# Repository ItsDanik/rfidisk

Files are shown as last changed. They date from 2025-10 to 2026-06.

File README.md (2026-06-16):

rfidisk_logo_hires

# 💾 RFIDisk — Physical App Launcher for Linux PC

**RFIDisk** turns RFID tags into *physical shortcuts* that launch games, apps, or scripts when inserted on a retro-styled "floppy drive" reader. Think of it as a cross between an RFID scanner and a USB floppy disk drive.  

https://github.com/user-attachments/assets/157f7cc6-f476-471f-b4b7-5301d1c28b9b

---

## What it is
This project is a combination of hardware and software:  

### Hardware
- An microcontroller device (Arduino), attached to an RFID reader module and an OLED display module, connected to the host machine via USB. It has its own 3D printed case design, resembling an external floppy disk drive.
- 3D Printed "Floppies" (they're not really floppy), with the RFID tag embedded in the print (invisible). Real floppies can be used instead, if you have an abundance of faulty ones.  

### Software
- The software is again a combination of two pieces of software:  
- One running on the arduino (we'll call it firmware).  
- The other one running on the host machine (Linux PC).  
- The two applications talk between them via Serial USB.
- Configuration and Tag Management is done via RFIDisk Manager (GUI App).

3D  

---

## How It Works
- Each RFID tag inside the disk corresponds to a command (e.g. `steam steam://rungameid/12345`).
1. When a disk is inserted in the drive, the Arduino firmware identifies it and notifies the host.  
2. The Python service looks up the tag’s command in `rfidisk_tags.json` and launches it.  
3. A notification is shown on the host machine.  
4. The OLED display updates in real time, showing metadata of the disk (user-configurable).  
5. When the disk is removed from the reader, the application is automatically terminated.  

This mode of operation closely resembles a cartridge-based game console system, only you don't have to reboot :)  






---

## WARNING!
> [!CAUTION]
Use this **at your own risk!!** This project contains a script that can pretty much execute whatever command the user wants. Do not import other people's configurations, except if you really know what you're doing. **Always** manually check the configuration file for malicious commands!

> [!IMPORTANT]
This project, including this README, are work in progress. There may be bugs, typos, errors, omissions etc.

---

## What you'll need
### Bill of Materials:

- 1x Arduino UNO (or compatible)  
- 1x 1.3" OLED 128x64 Display (**SH1106 controller**)  
- 1x RFID Reader Module (**MFRC522**)  
- 11x Jumper Wires ~15cm (Female to Male)  
- 1x USB Cable (type B to type A)
- 16x 4mm self-tapping M2 Screws  
- 4x 6mm self-tapping M2 Screws  
- 4x Rubber Feet  
- NFC NTAG213 25mm 13.56MHz (as many as you need, one per floppy)

### Tools:
- Soldering iron  
- 3D Printer  
- A PC running Linux  

---

## Hardware Assembly  

### Arduino Pinout  

Connect the devices to the arduino as shown below. 

> [!WARNING]  
> You will have to cut and solder on the RC522 board because of space restrictions, it won't fit the case otherwise.
> You can use connectors on all other connections (Arduino & OLED module).  

> [!CAUTION]  
> Connecting the RC522 board to 5V **WILL fry it!** Don't ask me how I know :)  
> Always double-check that 3.3V goes to RC522 and 5V goes to OLED module.  

```
RC522 VCC --- 3.3V  Arduino  
RC522 GND ---- GND  Arduino  
RC522 RST ------ 9  Arduino  
RC522 MISO ---- 12  Arduino  
RC522 MOSI ---- 11  Arduino  
RC522 SCK ----- 13  Arduino  
RC522 SDA ----- 10  Arduino  
 OLED VCC ----- 5V  Arduino  
 OLED GND ---- GND  Arduino  
 OLED SCL ----- A5  Arduino  
 OLED SDA ----- A4  Arduino  
```

###  Case

- Go to [https://makerworld.com/en/models/1875124-rfidisk-drive-disk](https://makerworld.com/en/models/1875124-rfidisk-drive-disk) and 3D print the project.  
- Screw the OLED module on the 3D Printed Shell using 4x 4mm screws.  
- Screw the two boards on the 3D Printed PCB Support Piece using 8x 4mm screws.  
- Screw the whole PCB Support to the top of the case (from the bottom) using 4x 4mm screws.  
- Screw the bottom 3D Printed part to the bottom of the shell using 4x 6mm screws.
- Stick the four rubber feet to the bottom of the case.
- Connect the device to the PC, using a USB type-B to type-A cable.

### RFIDisk Floppies

- Use the corresponding plate on the MakerWorld Project.
- Plate 4 is for single disk, plate 5 is for printing 4 disks in one go.
- The printing pauses on layer 7, that's when you go and stick the NFC tags on the designated area.
  Be careful to center the sticker. The sticker should not touch the walls of the area. Feel free
  to manually lower the bed using your printer's controls to get a better view/fit your hand.
- When you have placed the sticker(s) press resume. The printer will seal the NFC tags at the next layer.

> [!NOTE]
> You can also use real 3.5" floppy disks and stick the sticker at the center at the bottom (hub).
> If you experience weak signal and/or inconsistencies in reading, the metal surface of the disk is at fault.
> You can try to open carefully the disk and remove the whole disk, and stick the sticker through the hole on the inside.

---

## Software Installation / Configuration

### Project File Structure
This project consists of 10 files:  
```
- License             | Standard GNU GPL3.0 License  
- README.md           | What you're reading now.  
- floppy.png          | The icon that is being displayed in the desktop notifications.  
- install.sh          | Automatic installation script. You need to chmod +x it before you run it.  
- rfidisk.ino         | The arduino firmware. Written in C++. We will compile and upload this to the Arduino.  
- rfidisk.py          | The host software, running on our host machine. Wtieen in Python. This does the talking with the Arduino.  
- rfidisk_config.json | This is the settings file for the Python script (serial port, delays, notifications etc).  
- rfidisk_tags.json   | This is the RFID Tag database. Edit this file to configure RFID Tag behaviour.  
- rfidisk-manager.py  | The GUI that the user interacts with to configure RFIDisk and manage Tag entries.
- rfidisk_themes.py   | You can edit this file to add your own custom color scheme on RFIDisk Manager.  
- rfidisk.png         | RFIDisk asset image.  
```
>[!NOTE]  
>```rfidisk_config.json``` and ```rfidisk_tags.json``` are not included in the release or the repository.
>They are generated on first launch.  

---

## Download rfidisk
From ~/ or any subdirectory, type:  
```
git clone https://github.com/ItsDanik/rfidisk.git
cd rfidisk
```
>[!WARNING]
>It is suggested that you choose your home directory or any subdirectory in that folder!
>This is to ensure correct file permissions and save a lot of trouble.

---

## Installation using install script  
As of version 0.85 and later, there is an install script that can (hopefully) install everything with minimal user input.  
WARNING! Everything is beta, USE AT YOUR OWN RISK!!!  

```
chmod +x ./install.sh
./install.sh
```

>[!NOTE]
The script tries to autodetect distro/package manager, and automatically install all dependencies.  
If it stumbles, it will hopefully tell you what went wrong so you can manually install it and run the install script again.  

Log out and back in, or reboot. If everything went smoothly and you see "Ready/Insert Disk" on the device's OLED screen, congratulations!  

> [!NOTE]
> There is a 10 second delay in launching the app during boot. This is on purpose to ensure serial bus has settled and environment is set.  
> However, on some setups, there may be some instability (a couple of resets of the arduino) as the system enumerates the buses during boot.
> Give it a minute after a fresh boot/reboot and try again once the OLED screen consistently reads "Insert Disk".  

Skip to the "Configuring RFIDisk" section.  

## Updating RFIDisk
- From the install directory: 
```
git pull https://github.com/ItsDanik/rfidisk.git
chmod +x ./install.sh
./install.sh
```
The script should automatically detect the older version installed and will offer to update.  

> [!NOTE]
> All files (including the Firmware) are always updated on every release (even if there were no changes), to simplify version control and ensure that
> RFIDisk has the correct environment for its functions.  

## Uninstalling RFIDisk
- From the install directory:
```
./install.sh --uninstall
```

The app will not launch on next login, and the RFID Manager is removed from the start menu. Your settings and Tag Database remains saved.  
To remove everything (you will lose all your config!):  

```
cd ..
rm -rf rfidisk
```

---
## Manual Installation
If the install scripts fails, or you don't trust it, here are step by step instructions for manual installation of RFIDisk.  

### Prerequisites
The python script requires psutil and serial modules. Make sure to install them:  

```pip install pyserial psutil```  

>[!NOTE]
> If your distro whines when you use pip because it has an "externally managed python environment",
> install your libraries using your package manager (apt, dnf, pacman etc)

Also, you're going to need an Arduino dev environment. In this example we will use arduino-cli.  
The arduino sketch requires MFRC522, Adafruit GFX, and Adafruit SH110X libraries.  
Make sure to install them. If using arduino-cli:  

```
arduino-cli core install arduino:avr
arduino-cli lib install "Adafruit SH110X" "Adafruit GFX" MFRC522
``` 

The user should be able to get control of the serial port.  
This means that the user must be in the uucp or dialout group.  

```
sudo usermod -a -G dialout $(whoami)
sudo usermod -a -G uucp $(whoami)
```  

---

### Compiling and Uploading the arduino sketch  
If using arduino-cli, go into the directory of the project and type:  

```
arduino-cli compile rfidisk.ino -p /dev/ttyACM0 -b arduino:avr:uno
arduino-cli upload rfidisk.ino -p /dev/ttyACM0 -b arduino:avr:uno
```  

> [!WARNING]
> If your setup has another device path for the arduino, replace /dev/ttyACM0 with yours.  

If everything was succesful, the OLED Display should now show a logo (RFIDisk) and firmware version.  
To start RFIDisk manually, type:  
```
python3 ./rfidisk.py
```

---

## RFIDisk Manager
This is the app that you interact with to configure and manage RFIDisk.  
Open RFIDisk Manager via start menu.  

<img width="736" height="714" alt="2025-10-27T17:19:04,791128745+02:00" src="https://github.com/user-attachments/assets/de0971f7-7d53-4eab-9f25-93d7960ad6cb" />

### Configuring rfidisk
Open RFIDisk Manager (via start menu) and click on the Configuration Tab:  

<img width="427" height="311" alt="2025-10-27T17:23:16,570329816+02:00" src="https://github.com/user-attachments/assets/66e1eed4-a6e5-42bf-b207-2e9959f55ecf" />

```Theme```  

Select a color scheme for the RFIDisk Manager. The default installation includes Light, Dark and Catppuccin (Latte, Frappe, Macchiato, Mocha variants).  

>[!TIP]
>Themes are stored in rfidisk_themes.json. You can edit the file to add your own themes.

```Serial Port: /dev/ttyACM0```  

This is likely already correct. In case your device has a different path, enter it here.  
If have have more serial devices and want to set up a udev rule with a static custom path like /dev/rfidisk, to avoid mixups, keep reading.  

```Removal Delay (seconds): 0.0```  

This ensures that a disk is not ejected by mistake. If you reinsert the disk during that time, the removal is not registered, and the app is not terminated.  

```Disable Autolaunch```  

This changes the behaviour of RFIDisk to NOT autolaunch the command associated with the disk. See below, "CLI Mode" for details.

```Desktop Notifications```  

This enables desktop notifications when a disk is inserted. Disable it if you want to disable desktop notifications.   

```Notification Timeout (ms): 8000```  

This works only when desktop_notifications is true. Determines the amount of time (in ms) that the notification will be displayed for.  

```"Auto Launch Manager```

When this is enabled, RFIDisk Manager automatically gets launched when the user inserts a new (or unconfigured) Tag.  

### Tag Management  
You can manage your Tag entries in this tab (add, remove, edit).  
Changes take effect immediately. Keep reading for details.  

---

## Using RFIDisk

RFIDisk should start automatically upon login if you installed it using the script.  

- The app should initialize, and on the OLED screen of the device you should be able to see a "Ready/Insert Disk" message. Insert a floppy into the drive.
- RFIDisk Manager should automatically pop open with a new entry already created and the Tag ID field automatically completed. Remove the disk now and edit the followind fields:  

<img width="378" height="262" alt="RFIDisk Manager New Tag" src="https://github.com/user-attachments/assets/38867cf5-7aa0-497f-9bf9-6268a00593ee" />

The Tag ID ("a1b2c3d4") at the top will be different and is the unique ID of the NFC tag. Don't touch this value.  
Launch command: Type here the command you want to execute when this disk is inserted. You can also browse for the executable.  
Display Line 1-4: These are the four lines of text that will be displayed on the OLED screen when this disk gets inserted.  
Usually the first two lines are used for the title of the application, Line 3 for release year and Line 4 for Developer/Publisher.  
Terminate command: Useful when launching Steam games (keep reading).  

> [!NOTE]
> - "Display Line 1" and "Display Line 2" get truncated at 20 characters.  
> - "Display Line 3" and "Display Line 4" get truncated at 14 characters (to make room for the icon).

Here is an example of an entry, properly configured and formatted:  

<img width="458" height="215" alt="RFIDisk Manager Full Tag" src="https://github.com/user-attachments/assets/12a1846b-84c0-450a-9090-86f507bb3483" />

>[!TIP]
>We can leave the "Terminate Command" blank for all native linux titles. The script is aware of the whole process tree and can sucessfully track and terminate most applications.  

Click on "Save Changes", quit the manager and insert the disk. The application should now launch!  
Remove the disk and the application closes.  
Repeat the configuration proccess for as many disks as you need.  

---

## Using RFIDisk (CLI mode)

If you disable autolaunch, you can control RFIDisk via a terminal, resembling the way disk drives worked in 8-bit home micros. With the daemon running, use the following command line arguments:

- ```rfidisk --list``` to display disk info
- ```rfidisk --load``` to launch the app corresponding to the Tag entry of the disk
- ```rfidisk --list-title``` to display the title of the disk entry in a single line format (useful for displaying in widgets like waybar etc).
- ```rfidisk --help``` displays a help message.  

> [!TIP]
> If you remove the disk while the application is running, it still terminates the app.

---

## Post-installation optimizations

### Create udev rules for static device path
If you have more than one serial devices, they might get mixed up if you rely on /dev/ttyACM0 path.  
We need to create a unique device path for the arduino.  
We'll create two udev rules, let's start with one that ensures USB serial ownership:  
```
sudo nano /etc/udev/rules.d/90-tty-acm.rules  
```
Paste this into the empty new file:  
```
SUBSYSTEM=="tty", KERNEL=="ttyACM[0-9]*", GROUP="uucp", MODE="0660", TAG+="uaccess"
```
Save the file (Ctrl-X, y)  

Now, another to set the symlink:  
```
sudo nano /etc/udev/rules.d/99-custom-serial.rules
```
Paste this into the empty new file:  
```
SUBSYSTEM=="tty", ATTRS{idVendor}=="2341", ATTRS{idProduct}=="0043", \
  SYMLINK+="rfidisk", GROUP="uucp", MODE="0660", TAG+="uaccess"
```
Save the file (Ctrl-X, y)

To apply:  
```
sudo udevadm control --reload-rules
sudo udevadm trigger
sudo udevadm settle
```
Unplug the RFIDisk drive and plug it back in. You should now see:  
```
ls -l /dev/rifidisk
```

If successful, remember to update the rfidisk_config.json file:  
```
"serial_port": "/dev/rfidisk",
```

---

## Bugs / Quirks:
### Proton Quirks
When an application is launched via proton (ie Windows games), during the USB ports enumeration on the host machine get reset, causing the arduino to resets briefly momentarily. This is a known issue with Proton, you can check it out [here](https://github.com/ValveSoftware/Proton/issues/6927).  
To combat this, as a workaround, an overly-complex connection recovery routine has been implemented, to avoid double launching of an app, and double notifications etc. It seems to be working ok, but it is a hack. If anyone finds a better way to handle this, like prevent the USB device from disconnecting when Proton initializes (completely hiding a USB port from proton?), please let me know.  

---

### Steam Games
To launch steam games, in the "command" field of the entry, use:  

```steam steam://rungameid/1234567```

where "1234567" is the gameid of the game you want to play. To find the gameid, just look at the url address of the Store page of the game. For example, Cyberpunk 2077's store page URL is  

```https://store.steampowered.com/app/1091500/Cyberpunk_2077/```  

This means, that the gameid of Cyberpunk 2077 is 1091500. But also, terminating games that were launched cannot be automated. We have to manually specify a "terminate" command, that's what this field is reserved for in rfid_config.json entries. To determine the command:  

- Run the game manually
- Open a proccess monitor (htop, btop etc)
- Find the name of the process
- The terminate command is "killall (name of the process)"
In the example of Cyberpunk 2077, the proccess name is "GameThread".

After all this work, now we can build a Steam game entry:

<img width="380" height="217" alt="2025-10-14T18:30:53,591035808+03:00" src="https://github.com/user-attachments/assets/3febd89b-1f19-4c17-a427-bbf8b1351b25" />

---

### TODO/Ideas List

- Explore GameScope support (test game launching and make use of GameScope notification system).  
- Potentially package it as a DeckyLoader plugin?  

If ever:  
- Find a solution for the known issue with Proton (USB Momentarily Disconnects and Arduino reboots).

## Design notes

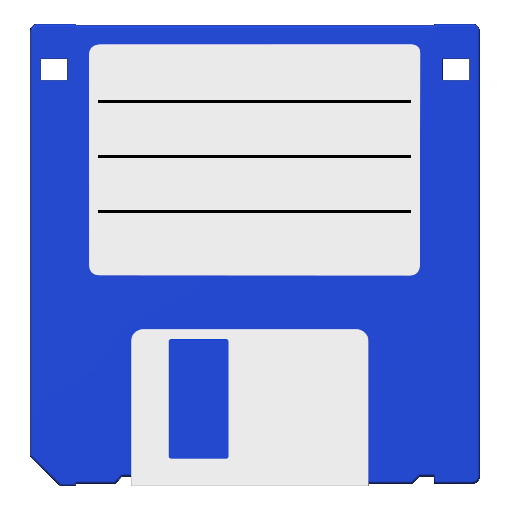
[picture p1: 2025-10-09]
floppy.png

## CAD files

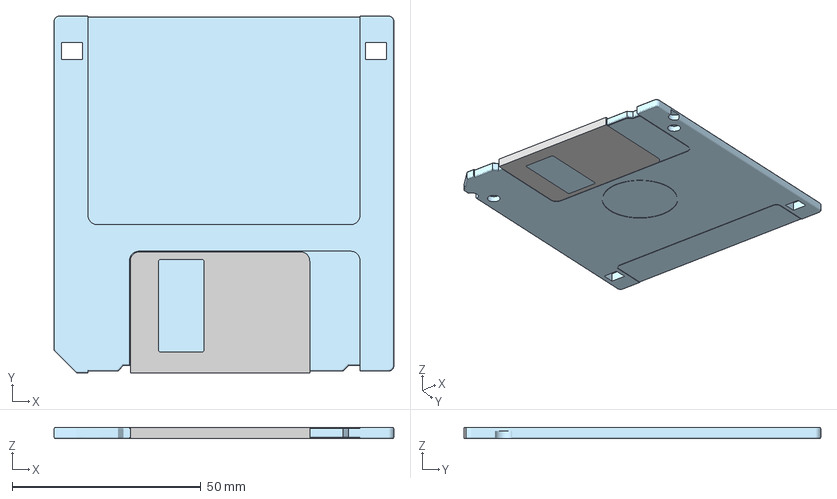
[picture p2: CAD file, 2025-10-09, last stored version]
3MF/RFIDisk V2.3mf
90.0 x 94.5 x 3.00 mm
Clip

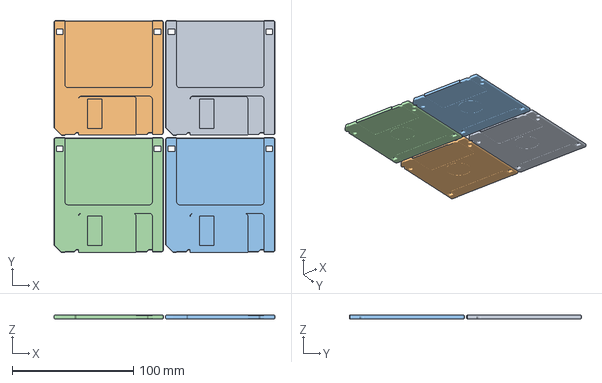
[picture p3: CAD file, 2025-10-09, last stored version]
danik floppy.3mf
182.0 x 191.0 x 3.00 mm
Assembly x 4

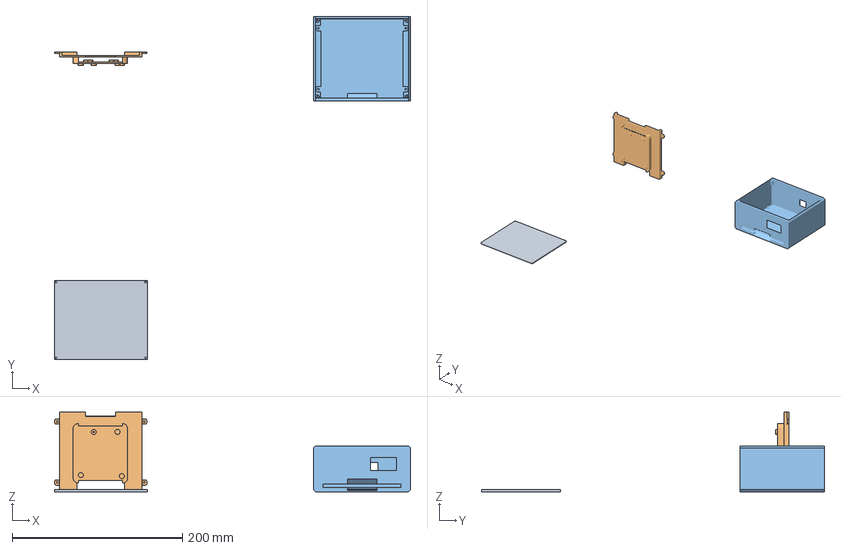
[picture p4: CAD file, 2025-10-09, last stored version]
Floppy RFID Scanner.3mf
419.1 x 403.3 x 93.5 mm
Bottom
Floppy RFID - PCB Support
RFID Floppy Shell

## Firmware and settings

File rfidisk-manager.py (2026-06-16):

#!/usr/bin/env python3
import tkinter as tk
from tkinter import ttk, messagebox, filedialog, simpledialog
import json
import os
import subprocess
import sys
import socket
import psutil
import time
import threading
import tempfile
from PIL import Image, ImageTk
import webbrowser

# Directory where this script lives, so the manager works regardless of CWD
SCRIPT_DIR = os.path.dirname(os.path.abspath(__file__))

# Use absolute paths for all data files (do not rely on the current directory)
TAGS_FILE = os.path.join(SCRIPT_DIR, "rfidisk_tags.json")
CONFIG_FILE = os.path.join(SCRIPT_DIR, "rfidisk_config.json")
THEME_FILE = os.path.join(SCRIPT_DIR, "rfidisk_theme.json")
VERSION_FILE = os.path.join(SCRIPT_DIR, "version")
LOGO_FILE = os.path.join(SCRIPT_DIR, "rfidisk.png")
LOCK_PORT = 47821
GITHUB_URL = "https://github.com/ItsDanik/rfidisk"


def read_version():
    """Read the version string from the shared 'version' file"""
    try:
        with open(VERSION_FILE, 'r') as f:
            return f.read().strip()
    except Exception:
        return "unknown"


def atomic_write_json(path, data):
    """Write JSON to path atomically.

    Writes to a temp file in the same directory, fsyncs it, then os.replace()s
    it over the target so a crash mid-write can never corrupt the existing file.
    """
    dir_name = os.path.dirname(path) or "."
    fd, tmp_path = tempfile.mkstemp(dir=dir_name, prefix=".tmp-", suffix=".json")
    try:
        with os.fdopen(fd, 'w') as f:
            json.dump(data, f, indent=2)
            f.flush()
            os.fsync(f.fileno())
        os.replace(tmp_path, path)
    except Exception:
        try:
            os.remove(tmp_path)
        except OSError:
            pass
        raise


# Version number (single source of truth: the 'version' file)
VERSION = read_version()

# Default fallback theme with semantic UI element names
COLORS = {
    # Background colors
    "bg_primary": "#1e1e2e",
    "bg_secondary": "#181825",
    "bg_tertiary": "#11111b",
    
    # Text colors
    "text_primary": "#cdd6f4",
    "text_secondary": "#bac2de",
    "text_tertiary": "#a6adc8",
    "text_warning": "#f38ba8",
    "text_success": "#a6e3a1",
    
    # Surface colors
    "surface_primary": "#313244",
    "surface_secondary": "#45475a",
    "surface_tertiary": "#585b70",
    
    # Border colors
    "border_primary": "#313244",
    "border_secondary": "#45475a",
    
    # Accent colors
    "accent_primary": "#89b4fa",
    "accent_secondary": "#74c7ec",
    "accent_success": "#a6e3a1",
    "accent_warning": "#f9e2af",
    "accent_error": "#f38ba8",
    "accent_highlight": "#fab387"
}

class SingletonApp:
    """Prevent multiple instances and handle inter-process communication"""
    def __init__(self):
        self.socket = None
        self.is_primary = False
        self.listening = False
        
    def acquire_lock(self):
        """Try to bind to a socket - if successful, we're the first instance"""
        try:
            self.socket = socket.socket(socket.AF_INET, socket.SOCK_STREAM)
            self.socket.setsockopt(socket.SOL_SOCKET, socket.SO_REUSEADDR, 1)
            self.socket.bind(('localhost', LOCK_PORT))
            self.socket.listen(1)
            self.socket.setblocking(False)
            self.is_primary = True
            return True
        except socket.error:
            return False
    
    def send_to_primary(self, tag_id=None):
        """Send a message to the primary instance"""
        try:
            client_socket = socket.socket(socket.AF_INET, socket.SOCK_STREAM)
            client_socket.settimeout(1.0)
            client_socket.connect(('localhost', LOCK_PORT))
            if tag_id:
                client_socket.send(f"EDIT:{tag_id}".encode())
            else:
                client_socket.send("FOCUS".encode())
            client_socket.close()
            return True
        except socket.error:
            return False
    
    def check_for_messages(self):
        """Check for incoming messages from other instances"""
        if not self.is_primary or not self.socket or not self.listening:
            return None
            
        try:
            client, addr = self.socket.accept()
            client.setblocking(True)
            data = client.recv(1024).decode().strip()
            client.close()
            return data
        except BlockingIOError:
            return None
        except socket.error:
            return None
    
    def start_listening(self):
        """Start listening for messages"""
        self.listening = True
    
    def stop_listening(self):
        """Stop listening for messages"""
        self.listening = False
    
    def cleanup(self):
        """Clean up socket resources"""
        self.stop_listening()
        if self.socket:
            self.socket.close()
            self.socket = None

class TagManager:
    def __init__(self, root):
        self.root = root
        self.root.title(f"RFIDisk Tag Manager v{VERSION}")
        self.root.geometry("740x720")
        
        # Load theme configuration
        self.themes = {}
        self.current_theme_name = "Catppuccin Mocha"
        self.load_theme_config()
        
        # Singleton management
        self.singleton = SingletonApp()
        self.setup_singleton()
        
        self.tags = self.load_tags()
        self.config = self.load_config()
        self.current_tag = None
        self.display_mode = "line1"

        # Live disk monitoring state (populated by the background `rfidisk --list` poller)
        self.inserted_tag_id = None          # tag_id of the currently inserted disk (None if empty)
        self.inserted_blank_tag_id = None    # set when the inserted disk is blank/unassigned
        self._highlight_tag_id = None        # tag_id to visually mark in the list (inserted + registered)
        self._disk_monitor_stop = threading.Event()

        # Load logo image
        self.logo_image = None
        self.load_logo()

        self.create_widgets()
        self.refresh_tag_list()

        # Start IPC handler after UI is fully set up
        self.root.after(100, self.setup_ipc_handler)

        # Start polling the inserted disk's contents via `rfidisk --list`
        self.start_disk_monitor()
    
    def load_theme_config(self):
        """Load theme configuration from file"""
        global COLORS
        
        try:
            with open(THEME_FILE, 'r') as f:
                theme_config = json.load(f)
            
            # Load available themes
            self.themes = theme_config.get("themes", {})
            
            # Get current theme name
            self.current_theme_name = theme_config.get("current_theme", "Catppuccin Mocha")
            
            # Load current theme colors
            if self.current_theme_name in self.themes:
                COLORS = self.themes[self.current_theme_name].copy()
                print(f"Loaded theme: {self.current_theme_name}")

                # Apply the color scheme
                self.configure_theme()

            else:
                print(f"Theme '{self.current_theme_name}' not found in theme file")
                
        except Exception as e:
            print(f"Failed to load theme config: {e}")
    
    def save_theme_config(self, theme_name):
        """Save current theme to configuration file"""
        try:
            with open(THEME_FILE, 'r') as f:
                theme_config = json.load(f)
            
            theme_config["current_theme"] = theme_name

            atomic_write_json(THEME_FILE, theme_config)

            print(f"Theme saved: {theme_name}")
            return True
        except Exception as e:
            print(f"Failed to save theme config: {e}")
            return False
    
    def change_theme(self, theme_name):
        """Change the current theme"""
        global COLORS
        
        if theme_name in self.themes:
            # Update global colors
            COLORS = self.themes[theme_name].copy()
            self.current_theme_name = theme_name
            
            # Save theme selection
            self.save_theme_config(theme_name)
            
            # Reconfigure theme
            self.configure_theme()
            
            # Update UI elements that need manual color updates
            self.update_theme_colors()
            
            return True
        else:
            return False
    
    def update_theme_colors(self):
        """Update UI elements that need manual color updates after theme change"""
        # Update root window background
        self.root.configure(bg=COLORS["bg_primary"])
        
        # Update warning labels and other non-ttk widgets
        for widget in self.root.winfo_children():
            self._update_widget_colors(widget)
    
    def _update_widget_colors(self, widget):
        """Recursively update widget colors"""
        try:
            if isinstance(widget, tk.Label):
                # Update background
                if widget.cget('bg') in [COLORS["bg_primary"], COLORS["bg_secondary"], COLORS["bg_tertiary"]]:
                    widget.configure(bg=COLORS["bg_primary"])
                
                # Update text colors
                current_fg = widget.cget('fg')
                if current_fg == COLORS.get("text_warning", "#f38ba8"):
                    widget.configure(fg=COLORS["text_warning"])
                elif current_fg == COLORS.get("accent_highlight", "#fab387"):
                    widget.configure(fg=COLORS["accent_highlight"])
                else:
                    widget.configure(fg=COLORS["text_primary"])
                    
        except tk.TclError:
            pass
        
        # Recursively update child widgets
        for child in widget.winfo_children():
            self._update_widget_colors(child)
    
    def load_logo(self):
        """Load the RFIDisk logo image"""
        logo_path = LOGO_FILE
        if os.path.exists(logo_path):
            try:
                image = Image.open(logo_path)
                if image.size != (400, 100):
                    image = image.resize((400, 100), Image.Resampling.LANCZOS)
                self.logo_image = ImageTk.PhotoImage(image)
            except Exception as e:
                print(f"Failed to load logo: {e}")
                self.logo_image = None
        else:
            print(f"Logo file not found: {logo_path}")
            self.logo_image = None
    
    def open_github(self):
        """Open the GitHub repository in the default web browser"""
        webbrowser.open(GITHUB_URL)
    
    def create_clickable_logo(self, parent):
        """Create a clickable logo that opens the GitHub repository"""
        if self.logo_image:
            logo_label = tk.Label(parent, image=self.logo_image, bg=COLORS["bg_primary"], cursor="hand2")
            logo_label.pack(pady=(0, 10))
            
            logo_label.bind("<Button-1>", lambda e: self.open_github())
            
            def on_enter(e):
                logo_label.config(bg=COLORS["surface_primary"])
            
            def on_leave(e):
                logo_label.config(bg=COLORS["bg_primary"])
            
            logo_label.bind("<Enter>", on_enter)
            logo_label.bind("<Leave>", on_leave)
            
            return logo_label
        return None
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

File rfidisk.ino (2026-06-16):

#include <SPI.h>
#include <MFRC522.h>
#include <Wire.h>
#include <EEPROM.h>
#include <Adafruit_GFX.h>
#include <Adafruit_SH110X.h>

#define RST_PIN 9
#define SS_PIN 10

Adafruit_SH1106G display(128, 64, &Wire, -1);
MFRC522 mfrc522(SS_PIN, RST_PIN);

bool tagPresent = false;
String lastTagUid = "";
const char version[] PROGMEM = "v0.97";

// OLED burn-in protection: idle dim / screen-off timers (set over serial via "C|")
unsigned long lastActivity = 0;
unsigned long dimDelayMs = 0;        // 0 = disabled
unsigned long offDelayMs = 0;        // 0 = disabled
byte powerState = 0;                 // 0 = active, 1 = dimmed, 2 = off
const byte CONTRAST_FULL = 0xCF;     // SH1106 default brightness
const byte CONTRAST_DIM  = 0x10;

// EEPROM persistence for the idle timers (survives reboots / works before the
// daemon connects). Signature byte guards against reading an uninitialised chip.
#define EE_SIG_ADDR 0
#define EE_DIM_ADDR 1
#define EE_OFF_ADDR 5
#define EE_SIG      0xA7

const unsigned char rfidisk_logo[] PROGMEM = {
0xfc, 0x7f, 0x77, 0xe1, 0xc0, 0x1c, 0x00, 0xe6, 0x70, 0x77, 0x31, 0xc0, 0x1c, 0x00, 0xe6, 0x70, 
	0x77, 0x18, 0x00, 0x1c, 0x00, 0xe7, 0x70, 0x77, 0x19, 0xc7, 0x1c, 0xc0, 0xe6, 0x70, 0x77, 0x19, 
	0xcd, 0x9d, 0x80, 0xe6, 0x7f, 0x77, 0x19, 0xdc, 0x1d, 0x80, 0xfc, 0x70, 0x77, 0x19, 0xcf, 0x1f, 
	0x00, 0xec, 0x70, 0x77, 0x19, 0xc7, 0x9f, 0x00, 0xe4, 0x70, 0x77, 0x19, 0xc1, 0x9f, 0x80, 0xe6, 
	0x70, 0x77, 0x31, 0xd9, 0x9d, 0x80, 0xe7, 0x70, 0x77, 0xe1, 0xcf, 0x1c, 0xc0
};

// 'icon_floppy', 24x24px
const unsigned char floppy_icon[] PROGMEM = {
	0x7f, 0xff, 0xfe, 0x40, 0x00, 0x02, 0x47, 0xff, 0xe2, 0x57, 0xff, 0xea, 0x47, 0xff, 0xe2, 0x47, 
	0xff, 0xe2, 0x47, 0xff, 0xe2, 0x47, 0xff, 0xe2, 0x47, 0xff, 0xe2, 0x47, 0xff, 0xe2, 0x47, 0xff, 
	0xe2, 0x47, 0xff, 0xe2, 0x43, 0xff, 0xc2, 0x40, 0x00, 0x02, 0x40, 0x00, 0x02, 0x41, 0xff, 0x82, 
	0x41, 0x1f, 0x82, 0x41, 0x1f, 0x82, 0x41, 0x1f, 0x82, 0x41, 0x1f, 0x82, 0x41, 0x1f, 0x82, 0x21, 
	0xff, 0x82, 0x10, 0x00, 0x02, 0x0f, 0xff, 0xfe
};

// 'icon_steam', 24x24px
const unsigned char steam_icon[] PROGMEM = {
	0x00, 0x7e, 0x00, 0x01, 0xff, 0x80, 0x07, 0xff, 0xe0, 0x0f, 0xff, 0xf0, 0x1f, 0xfc, 0x38, 0x3f, 
	0xf0, 0x0c, 0x3f, 0xf3, 0xcc, 0x7f, 0xe4, 0x26, 0x7f, 0xe4, 0x26, 0xff, 0xe4, 0x27, 0xff, 0xc4, 
	0x27, 0x7f, 0xc3, 0xcf, 0x0f, 0x80, 0x0f, 0x02, 0x00, 0x3f, 0x00, 0xc3, 0xff, 0x00, 0x27, 0xfe, 
	0x60, 0x2f, 0xfe, 0x38, 0x2f, 0xfc, 0x3d, 0xdf, 0xfc, 0x1e, 0x3f, 0xf8, 0x0f, 0xff, 0xf0, 0x07, 
	0xff, 0xe0, 0x01, 0xff, 0x80, 0x00, 0x7e, 0x00
};

// Send a raw command byte to the SH1106 (Adafruit_SH110X exposes no public
// power/contrast control, so we talk to the panel directly over I2C).
void oledCommand(uint8_t c) {
  Wire.beginTransmission(0x3C);
  Wire.write(0x00);   // control byte: Co=0, D/C#=0 -> command stream
  Wire.write(c);
  Wire.endTransmission();
}

void setPowerState(byte s) {
  if (s == powerState) return;
  switch (s) {
    case 1: // dimmed
      oledCommand(0xAF);                       // ensure panel on
      oledCommand(0x81); oledCommand(CONTRAST_DIM);
      break;
    case 2: // off
      oledCommand(0xAE);                       // panel off
      break;
    default: // 0 = active
      oledCommand(0xAF);
      oledCommand(0x81); oledCommand(CONTRAST_FULL);
      break;
  }
  powerState = s;
}

// Any activity (display update, new config) wakes the panel and resets idle.
void wakeDisplay() {
  lastActivity = millis();
  setPowerState(0);
}

void loadConfigFromEEPROM() {
  if (EEPROM.read(EE_SIG_ADDR) == EE_SIG) {
    EEPROM.get(EE_DIM_ADDR, dimDelayMs);
    EEPROM.get(EE_OFF_ADDR, offDelayMs);
  }
  // Uninitialised EEPROM -> leave timers at 0 (disabled) until configured.
}

void saveConfigToEEPROM() {
  EEPROM.update(EE_SIG_ADDR, EE_SIG);
  EEPROM.put(EE_DIM_ADDR, dimDelayMs);   // put() only rewrites changed bytes
  EEPROM.put(EE_OFF_ADDR, offDelayMs);
}

void setup() {
  Serial.begin(9600);

  // Restore persisted idle timers before anything draws to the panel
  loadConfigFromEEPROM();
  
  // Initialize display
  if (!display.begin(0x3C, false)) {
    // If display fails, continue anyway
  }

  // Show boot screen
  display.clearDisplay();
  display.drawBitmap(39, 28, rfidisk_logo, 50, 11, SH110X_WHITE);
  display.setTextColor(SH110X_WHITE);
  display.setCursor(98, 56);
  display.print((const __FlashStringHelper*)version);
  display.display();
  delay(800);
  
  // Initialize RFID
  SPI.begin();
  mfrc522.PCD_Init();

  lastActivity = millis();

  Serial.println("OK");
}

void updateDisplay(const char* line1, const char* line2, const char* line3, const char* line4, byte iconType) {
  wakeDisplay();  // new content -> panel on, full brightness, reset idle timer
  display.clearDisplay();
  display.setTextColor(SH110X_WHITE);
  display.setTextSize(1);

  // Top section (line1 and line2)
  display.setCursor(5, 8);
  display.print(line1);
  
  display.setCursor(5, 20);
  display.print(line2);

  // Horizontal divider line
  display.drawLine(0, 31, 128, 31, SH110X_WHITE);

  // Bottom section (line3 and line4)
  display.setCursor(5, 40);
  display.print(line3);
  
  display.setCursor(5, 52);
  display.print(line4);

  // Draw icon in bottom right based on iconType
  if (iconType > 0) {
    switch(iconType) {
      case 1: // Floppy disk icon
        display.drawBitmap(100, 36, floppy_icon, 24, 24, SH110X_WHITE);
        break;
      case 2: // Steam icon
        display.drawBitmap(100, 36, steam_icon, 24, 24, SH110X_WHITE);
        break;
      // Add more cases for different icon types later
      default:
        break;
    }
  }

  display.display();
}

String getTagUid() {
  String uid = "";
  for (byte i = 0; i < mfrc522.uid.size; i++) {
    if (mfrc522.uid.uidByte[i] < 0x10) uid += "0";
    uid += String(mfrc522.uid.uidByte[i], HEX);
  }
  return uid;
}

bool isTagPresent() {
  // Reset the reader
  mfrc522.PCD_Init();
  delay(10);
  
  if (!mfrc522.PICC_IsNewCardPresent()) {
    return false;
  }
  
  if (!mfrc522.PICC_ReadCardSerial()) {
    return false;
  }
  
  return true;
}
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

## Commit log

2025-10-09 Rename Floppy RFID Scanner.3mf to RFIDisk Drive.3mf
    [RFIDisk Drive.3mf]
2025-10-09 Rename danik floppy.3mf to Floppy RFIDisk.3mf
    [Floppy RFIDisk.3mf]
2025-10-09 Rename Floppy RFIDisk.3mf to 3MF/Floppy RFIDisk.3mf
    [Floppy RFIDisk.3mf]
2025-10-09 Rename RFIDisk Drive.3mf to 3MF/RFIDisk Drive.3mf
    [RFIDisk Drive.3mf]
2025-10-09 Update rfidisk.py
    Replaced all instances of "rfid_config.json" to "rfidisk_config.json"
    [rfidisk.py]
2025-10-09 Update rfidisk.py
    Replace "floppy.webp" with "floppy.png"
    [rfidisk.py]
2025-10-09 Update rfidisk.py
    Removed windows support (it was mostly broken)
    Added warning on console output upon initialization (potentiously malicious executables in config)
    [rfidisk.py]
2025-10-09 Delete 3MF/Floppy RFIDisk.3mf
    To be replaced with better optimized model.
    [Floppy RFIDisk.3mf]
2025-10-09 Rename RFIDisk V2.3mf to 3MF/RFIDisk V2.3mf
    [RFIDisk V2.3mf]
2025-10-10 Update rfidisk.py
    v0.5:
    - Strings are now truncated at 20 characters during runtime. This saves RAM on the Arduino, but also prevents text overflow/overlay.
    - Improved notification.
    [rfidisk.py]
2025-10-10 Update rfidisk.py
    Added detection of steam games (to display steam icon on Arduino)
2025-10-10 Update rfidisk.ino
    Added support for Steam Icon.
    Now steam games will display a steam logo on the bottom right on the OLED screen of the device.
2025-10-10 Delete 3MF directory
    3D Models will be hosted on MakerWorld from now on
    [RFIDisk Drive.3mf, RFIDisk V2.3mf]
2025-10-11 Update rfidisk.ino
    v0.8
    -Icons are now 24x24 pixels (saves program memory)
    -Fw version is now stored in program memory, preventing heap fragmentation caused by String objects dynamically allocating memory
    [rfidisk.ino]
2026-06-16 Release v0.96
    Bug fixes:
    - Correct serial port defaults: rfidisk.py used a non-existent default
    (/dev/ACM0) and a different reconnect fallback (/dev/rfidisk); both now
    default to /dev/ttyACM0, matching the manager. Fresh installs connect.
    - Stop mutating config defaults at runtime: load_config() used a shallow
    dict.copy() that mutated module-level default_config/default_tags; now
    uses copy.deepcopy().
    - Unify removal_delay default to 0.0 (the removal handler fell back to 2.0).
    - Remove dead process-tree tracking (get_full_process_tree /
    process_tree_pids were never used) and the now-unused psutil import.
    - Fix Hyprland detection in install.sh: operator precede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
    [rfidisk-manager.py, rfidisk.ino, rfidisk.py]
2026-06-16 RFIDisk Manager v0.97 — disk monitoring features & OLED burn-in protection
    - Live disk status in the bottom-left of all tabs auto-selects and
    highlights registered disks in the Configured Tags list for quick edit/delete.
    - OLED burn-in protection: the display now dims and then switches off after
    configurable idle periods. Two new settings in the Configuration tab,
    `oled_dim_delay` and `oled_off_delay` (seconds, 0 = disabled, default
    60/120), are pushed to the Arduino over serial (new `C|dimSec|offSec`
    command). The firmware does the idle timing itself, persists the values to
    EEPROM (remembered across reboots), and wakes the panel on any activity.
    [rfidisk-manager.py, rfidisk.ino, rfidisk.py]
